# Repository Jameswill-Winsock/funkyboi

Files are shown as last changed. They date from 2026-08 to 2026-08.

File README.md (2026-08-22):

# funkyboi
a funky chonky handheld gba clone

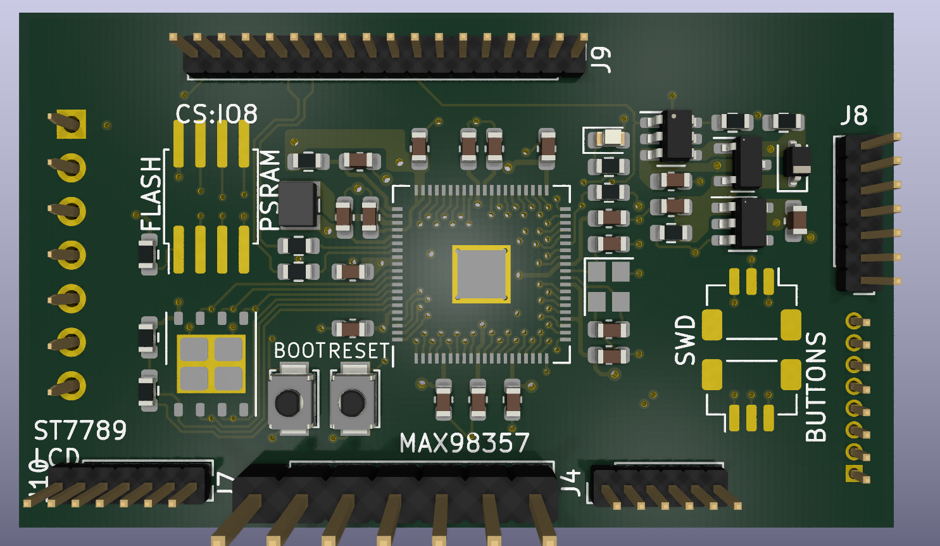
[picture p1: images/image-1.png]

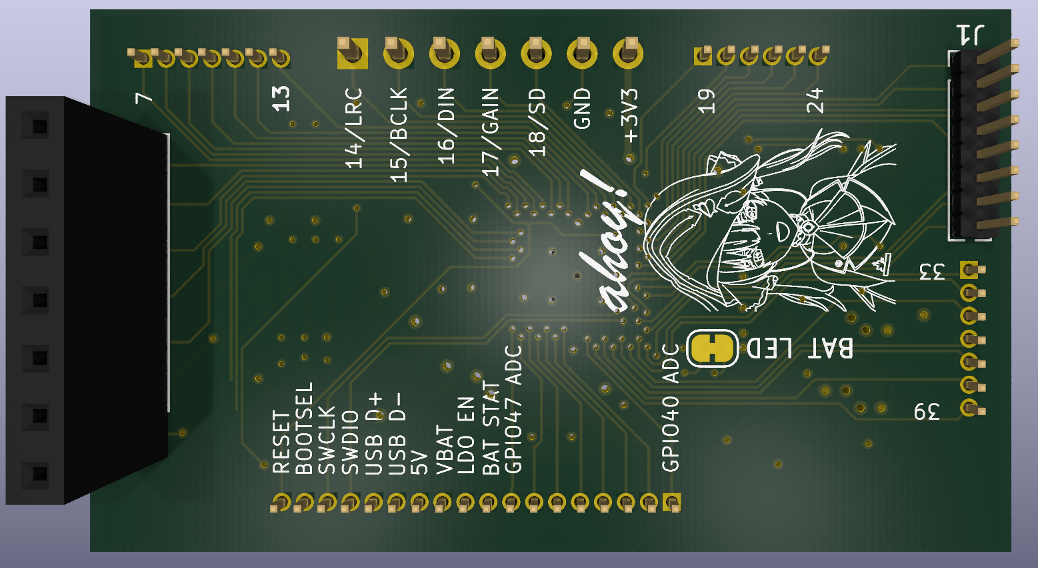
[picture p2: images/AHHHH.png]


he's a work in progress, please bear with him

## What is this?
like you read, a gba clone. its meant to be as small in form factor as possible, and currently i've nearly achieved this. 
it borrows from the solderparty stamp xl in form of the schematic, but pcb was remade because it wouldn't open for me for some reason. some differences between those and this are:
- lack of castelled edge based breakout (swapped to normal through holes)
- no proper power plane or signal plane (i have no idea how those work, i only know ground copper pour)
- power network significantly changed to be more unified (arguably, more unstable, but throw on some 100nf capacitors and it fixes everything.)
- the obvious gamer setup

## Parts used
please refer to "BOM reference.csv". Has everything for now,

## Journal.md
included please check

## Photos
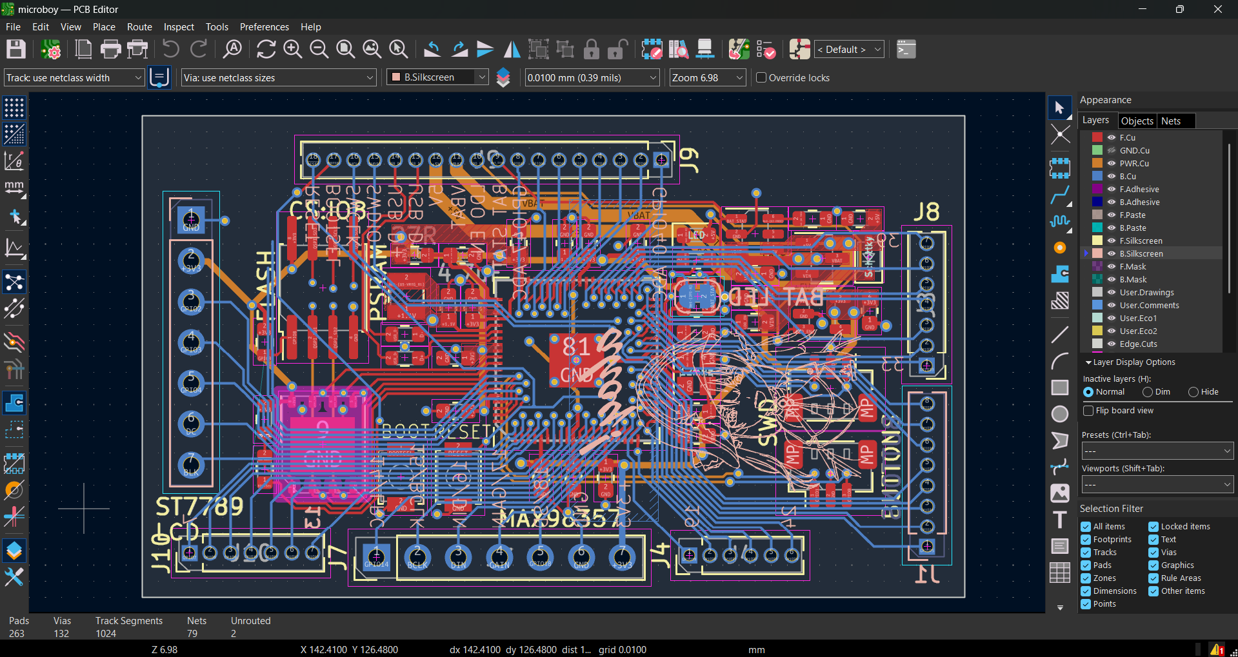
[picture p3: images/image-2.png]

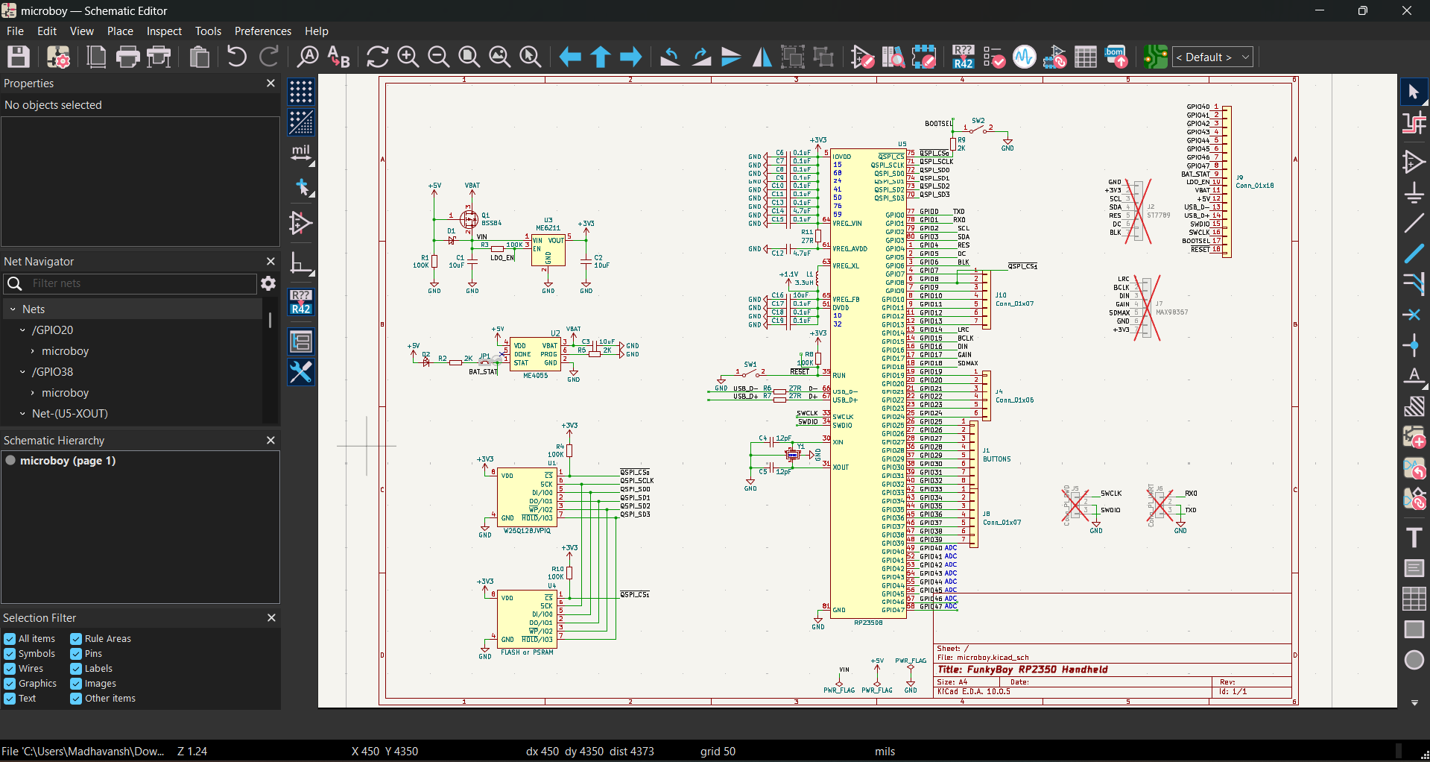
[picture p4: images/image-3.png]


yes i know the elephant in the room is the big red cross marks
they're marked do not populate because i want to leave the headers alone until i need them and for the actual parts that'll be needed i'll hand solder what i can

## Thanks
to you for coming here

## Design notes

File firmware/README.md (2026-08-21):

# Minimal bring-up firmware

quick and dirty test for the *funky* boi:
- ST7789V3 172x320 display on GPIO40..45
- 8 active-low buttons with pull-ups
- USB serial logging
- No PSRAM, flash filesystem, Doom, or audio yet

## Expected behavior
1. Boot -> LCD shows 8 color bars.
2. Then the loop goes black when no button is pressed.
3. Pressing each button fills the display with a unique color and prints button state over USB CDC serial.

## Pin map
LCD: MOSI 40, SCK 41, CS 42, DC 43, RST 44, BL 45
Buttons: UP 0, LEFT 1, RIGHT 2, DOWN 3, B 35, A 37, SELECT 18, START 24

## Build
Use a recent Raspberry Pi Pico SDK with RP2350 support.

```bash
mkdir build && cd build
cmake .. -DPICO_BOARD=pico2
make -j
```

Copy `microboy_bringup.uf2` to the RP2350 BOOTSEL drive.

## If the LCD is shifted / mirrored
This project assumes landscape 320x172 with a 34-pixel controller RAM offset and MADCTL=0x60.
If your panel orientation differs, adjust the MADCTL byte in `lcd_init()` and/or `yoff` in `lcd_window()`.

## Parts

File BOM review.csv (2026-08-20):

Reference | Value | Footprint | Qty | LCSC | Description
C4,C5 | 12pF | Capacitor_SMD:C_0603_1608Metric | 2
C6,C7,C8,C9,C10,C11,C13,C15,C17,C18,C19 | 0.1uF | Capacitor_SMD:C_0603_1608Metric | 11
L1 | 3.3uH | Inductor_SMD:L_Wuerth_MAPI-2512 | 1 | C5832359 | FTC252010S3R3MBCA
C12,C14 | 4.7uF | Capacitor_SMD:C_0603_1608Metric | 2
C1,C2,C3,C16 | 10uF | Capacitor_SMD:C_0603_1608Metric | 4
R6,R7,R11 | 27R | Resistor_SMD:R_0603_1608Metric | 3
R2,R5,R9 | 2K | Resistor_SMD:R_0603_1608Metric | 3
R1,R3,R4,R8,R10 | 100K | Resistor_SMD:R_0603_1608Metric | 5
SW8 | A | Button_Switch_SMD:SW_SPST_B3U-1000P | 1
SW7 | B | Button_Switch_SMD:SW_SPST_B3U-1000P | 1
Q1 | BSS84 | Package_TO_SOT_SMD:SOT-23 | 1 | C85202
Y1 | CM4012M00012001 | Crystal:Crystal_SMD_2520-4Pin_2.5x2.0mm | 1 | C7294611
J10,J11,J15,J16,J17,J19,J20 | Conn_01x01 | Connector_PinHeader_1.27mm:PinHeader_1x01_P1.27mm_Vertical | 7 |  | Generic connector, single row, 01x01, 1.27mm, through hole vertical
J9,J12,J13,J14,J18 | Conn_01x02 | Connector_PinHeader_1.27mm:PinHeader_1x02_P1.27mm_Vertical | 5 |  | Generic connector, single row, 01x02, 1.27mm, through hole vertical
J3 | Conn_01x05 | Connector_PinHeader_1.27mm:PinHeader_1x05_P1.27mm_Vertical | 1 |  | Generic connector, single row, 01x05, 1.27mm, through hole vertical
J1,J4 | Conn_01x10 | Connector_PinHeader_1.27mm:PinHeader_1x10_P1.27mm_Vertical | 2 |  | Generic connector, single row, 01x10, 1.27mm, through hole vertical
J5 | Conn_Pi_SWD | Connector_JST:JST_SH_BM03B-SRSS-TB_1x03-1MP_P1.00mm_Vertical | 1 | C7433439
J6 | Conn_Pi_UART | Connector_JST:JST_SH_BM03B-SRSS-TB_1x03-1MP_P1.00mm_Vertical | 1 | C7433439
D1 | D_Schottky_Small | Diode_SMD:D_SOD-323 | 1 | C114023 | B5817WS-SJ
SW6 | DOWN | Button_Switch_SMD:SW_SPST_B3U-1000P | 1
U4 | FLASH or PSRAM | Package_SO:SSOP-8_5.25x5.24mm_P1.27mm | 1
J8 | I2S_AUDIO | Connector_PinHeader_2.54mm:PinHeader_1x05_P2.54mm_Vertical | 1
J7 | LCD_ST7789 | Connector_PinHeader_2.54mm:PinHeader_1x08_P2.54mm_Vertical | 1
D2 | LED_CHR | LED_SMD:LED_0603_1608Metric | 1 |  | Orange
SW4 | LEFT | Button_Switch_SMD:SW_SPST_B3U-1000P | 1
U2 | ME4055 | Package_TO_SOT_SMD:SOT-23-6 | 1 | C82121
U3 | ME6211 | Package_TO_SOT_SMD:SOT-23-5 | 1 | C82942
SW5 | RIGHT | Button_Switch_SMD:SW_SPST_B3U-1000P | 1
U5 | RP2350B | Package_DFN_QFN_Extra:QFN-80_EP_10x10_Pitch0.4mm | 1
SW9 | SELECT | Button_Switch_SMD:SW_SPST_B3U-1000P | 1
SW10 | START | Button_Switch_SMD:SW_SPST_B3U-1000P | 1
SW2 | SW_BOOTSEL | Button_Switch_SMD:SW_SPST_B3U-1000P | 1 | C561514 | TS-3025-A-A-B
SW1 | SW_RESET | Button_Switch_SMD:SW_SPST_B3U-1000P | 1 | C561514 | TS-3025-A-A-B
SW3 | UP | Button_Switch_SMD:SW_SPST_B3U-1000P | 1
U1 | W25Q128JVPIQ | Package_SON:WSON-8-1EP_6x5mm_P1.27mm_EP3.4x4mm | 1 | C190862
LCD1 | Waveshare_1.47in_172x320_ST7789V3 |  | 1 |  | External Waveshare LCD module from supplied link; connects to existing J7 LCD_ST7789
AMP1 | MAX98357A_I2S_Audio_Module |  | 1 |  | External I2S mono Class-D amplifier module; connects to existing J8 I2S_AUDIO
SPK1 | 4R_3W_Speaker |  | 1 |  | External 4 ohm 2-3W speaker for MAX98357A OUT+/OUT-
USB1 | USB-C_5V_Power_Breakout |  | 1 |  | OPTION A: external USB-C 5V power breakout; connect VBUS to existing +5V input and GND to GND
J21 | USB_C_Receptacle_USB2.0_16P | Connector_USB:USB_C_Receptacle_HRO_TYPE-C-31-M-12 | 1 | C165948 | OPTION B: raw on-board USB-C receptacle; use instead of USB1
R12,R13 | 5.1K | Resistor_SMD:R_0603_1608Metric | 2 | C23186 | USB-C CC1/CC2 pull-down resistors; required only with raw J21 option
D3 | USBLC6-2SC6 | Package_TO_SOT_SMD:SOT-23-6 | 1 | C7519 | USB D+/D- ESD protection; use with raw USB-C data connection
J22 | BATTERY_1S | Connector_JST:JST_PH_B2B-PH-K_1x02_P2.00mm_Vertical | 1 | C131337 | JST-PH 2.0mm 2-pin connector for 1S LiPo or protected 18650 supply
BAT1 | 1S_LiPo_3.7V |  | 1 |  | OPTION A battery: protected 1S LiPo pack; capacity/size to suit enclosure
BT1 | 18650_Holder_1S |  | 1 |  | OPTION B battery: single 18650 holder
BMS1 | 1S_LiIon_Protection_BMS |  | 1 |  | 18650/cell only; protection-only BMS because existing ME4055 already handles charging
SW11 | POWER_ON_OFF | Button_Switch_SMD:SW_SPDT_CK_JS102011SAQN | 1 |  | SPDT slide power switch; can use existing LDO_EN/VIN/GND arrangement without changing core circuitry

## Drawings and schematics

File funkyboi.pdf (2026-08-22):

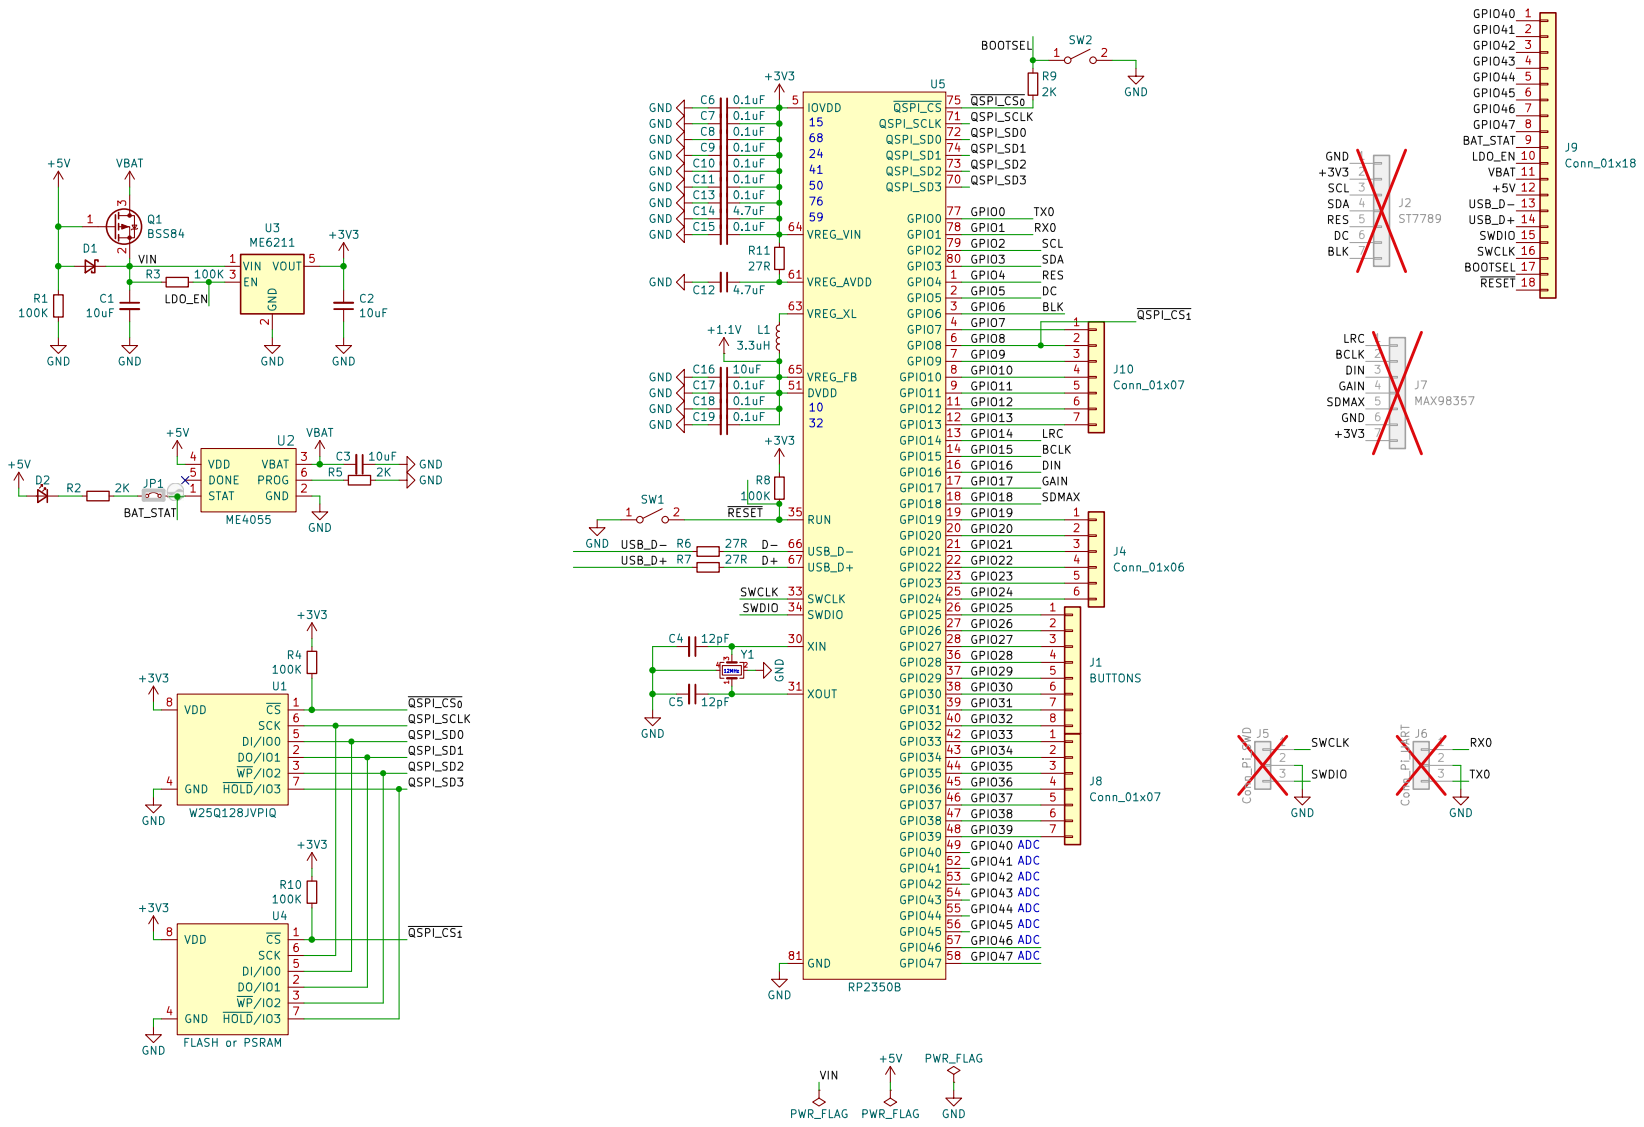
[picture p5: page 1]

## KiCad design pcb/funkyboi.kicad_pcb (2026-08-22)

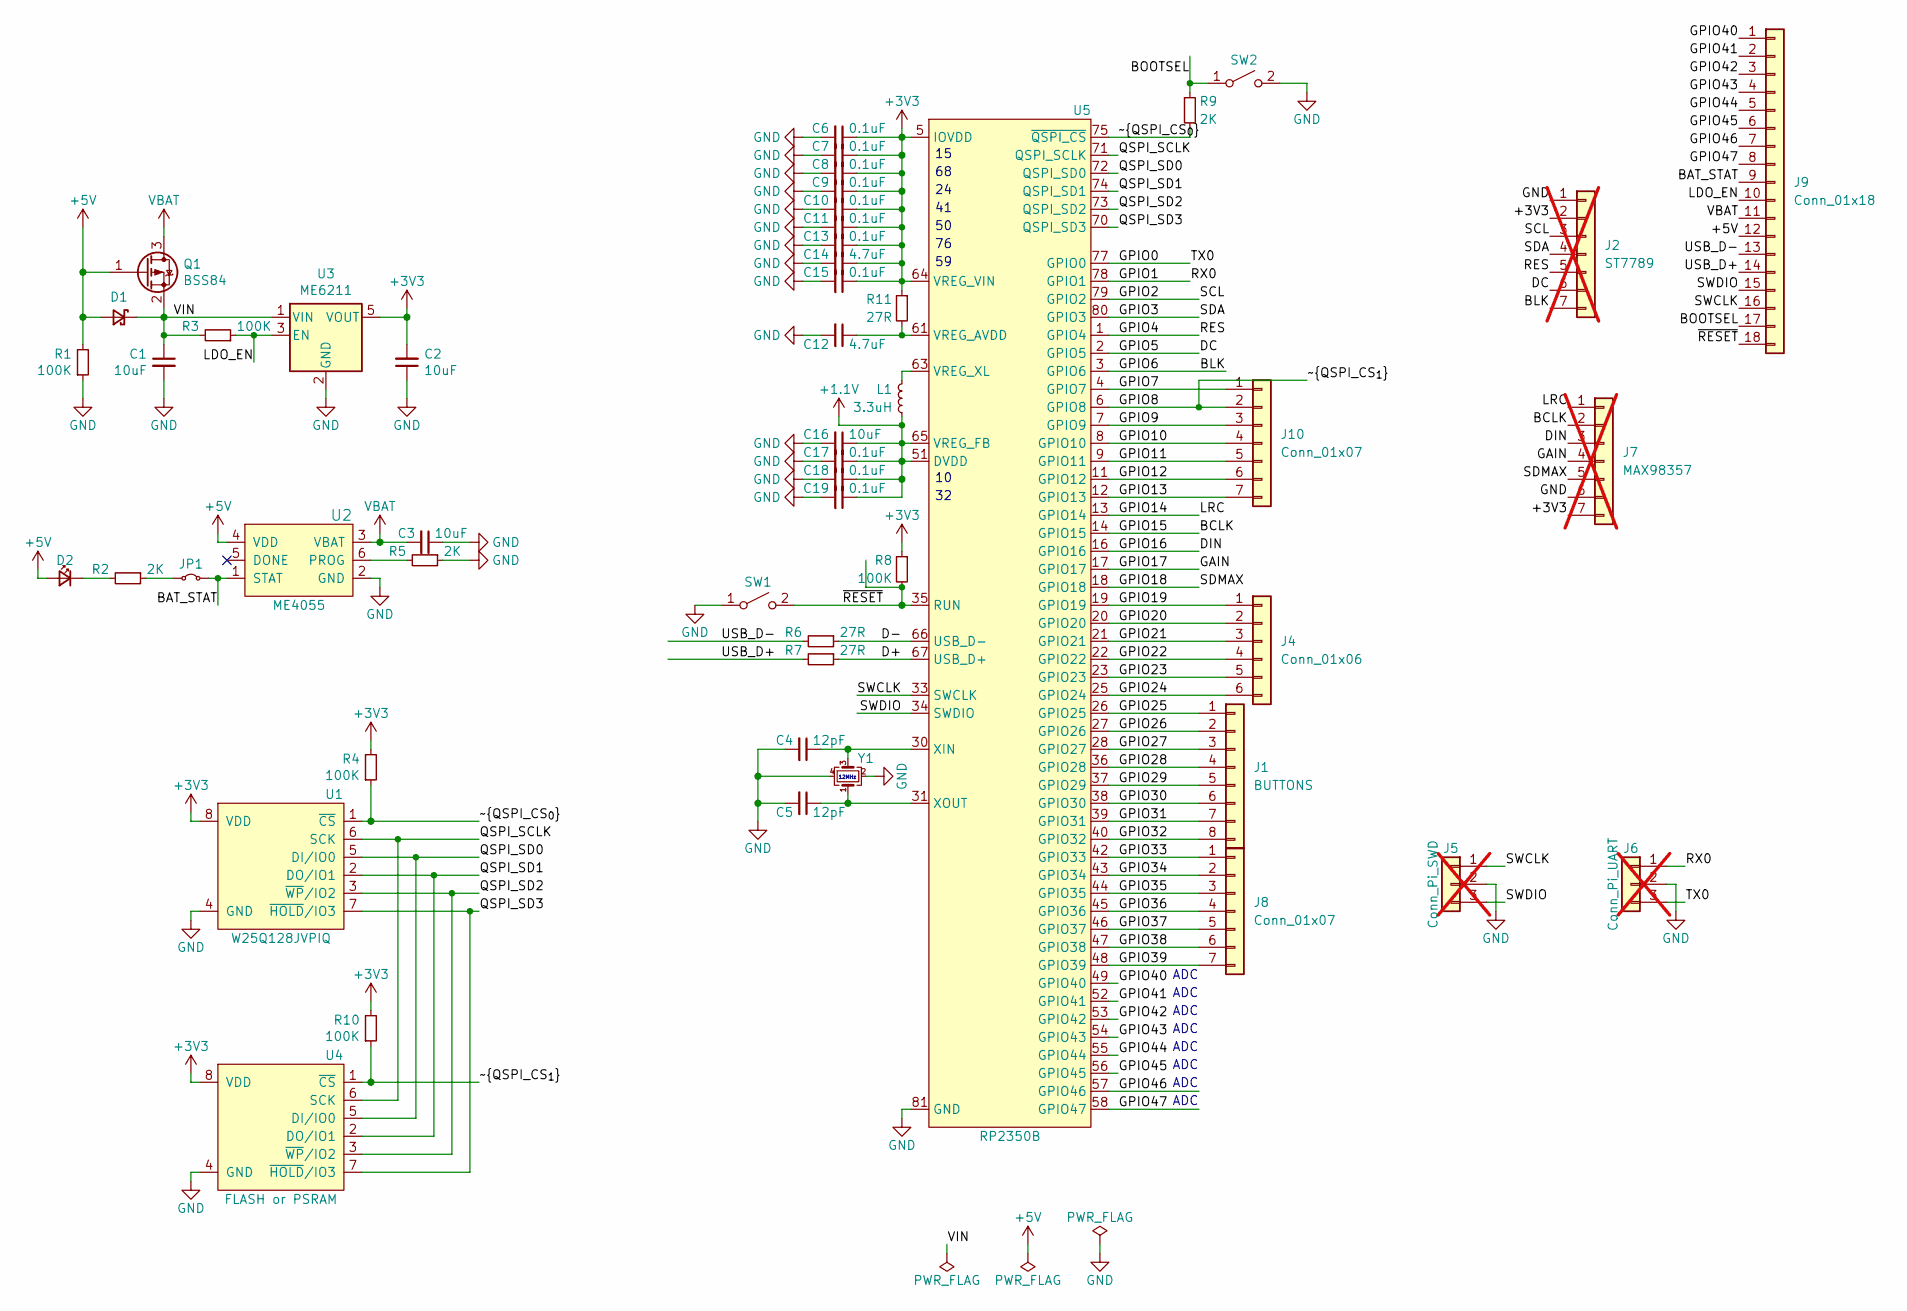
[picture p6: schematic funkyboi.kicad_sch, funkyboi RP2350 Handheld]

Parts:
C1, C2, C3, C16: 10uF; C_0603_1608Metric
C4, C5: 12pF; C_0603_1608Metric
C6, C7, C8, C9, C10, C11, C13, C15, C17, C18, C19: 0.1uF; C_0603_1608Metric
C12, C14: 4.7uF; C_0603_1608Metric
D1: D_Schottky_Small; D_SOD-323; LCSC C114023
D2: LED_CHR; LED_0603_1608Metric
J1: BUTTONS; PinHeader_1x08_P1.27mm_Vertical
J2: ST7789; PinSocket_1x07_P2.54mm_Vertical; not fitted
J4: Conn_01x06; PinHeader_1x06_P1.27mm_Vertical
J5: Conn_Pi_SWD; JST_SH_BM03B-SRSS-TB_1x03-1MP_P1.00mm_Vertical; LCSC C7433439; not fitted
J6: Conn_Pi_UART; JST_SH_BM03B-SRSS-TB_1x03-1MP_P1.00mm_Vertical; LCSC C7433439; not fitted
J7: MAX98357; PinHeader_1x07_P2.54mm_Vertical; not fitted
J8, J10: Conn_01x07; PinHeader_1x07_P1.27mm_Vertical
J9: Conn_01x18; PinHeader_1x18_P1.27mm_Vertical
JP1: SJ_STAT_LED; SolderJumper-2_P1.3mm_Bridged_RoundedPad1.0x1.5mm
L1: 3.3uH; L_Wuerth_MAPI-2512; LCSC C5832359
Q1: BSS84; SOT-23; LCSC C85202
R1, R3, R4, R8, R10: 100K; R_0603_1608Metric
R2, R5, R9: 2K; R_0603_1608Metric
R6, R7, R11: 27R; R_0603_1608Metric
SW1: SW_RESET; SW_SPST_B3U-1000P; LCSC C561514
SW2: SW_BOOTSEL; SW_SPST_B3U-1000P; LCSC C561514
U1: W25Q128JVPIQ; WSON-8-1EP_6x5mm_P1.27mm_EP3.4x4mm; LCSC C190862
U2: ME4055; SOT-23-6; LCSC C82121
U3: ME6211; SOT-23-5; LCSC C82942
U4: FLASH or PSRAM; SSOP-8_5.25x5.24mm_P1.27mm
U5: RP2350B; QFN-80_EP_10x10_Pitch0.4mm
Y1: CM4012M00012001; Crystal_SMD_2520-4Pin_2.5x2.0mm; LCSC C7294611

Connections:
+1.1V: C16.1, C17.1, C18.1, C19.1, L1.1, U5.10 (DVDD), U5.32 (DVDD), U5.51 (DVDD), U5.65 (VREG_FB)
+3V3: C2.2, C6.1, C7.1, C8.1, C9.1, C10.1, C11.1, C13.1, C14.1, C15.1, J2.2, J7.7, R4.2, R8.1, R10.2, R11.1, U1.8 (VDD), U3.5 (VOUT), U4.8 (VDD), U5.5 (IOVDD), U5.15 (IOVDD), U5.24 (IOVDD), U5.29 (IOVDD), U5.41 (IOVDD), U5.50 (IOVDD), U5.59 (IOVDD), U5.60 (IOVDD), U5.64 (VREG_VIN), U5.68 (IOVDD), U5.69 (IOVDD), U5.76 (IOVDD)
+5V: D1.2 (A), D2.2 (A), J9.12, Q1.1 (G), R1.2, U2.4 (VDD)
/BAT_STAT: J9.9, JP1.2 (B), U2.1 (STAT)
/BCLK: J7.2, U5.14 (GPIO15)
/BLK: J2.7, U5.3 (GPIO6)
/BOOTSEL: J9.17, R9.1, SW2.1 (A)
/D+: R7.1, U5.67 (USB_D+)
/D-: R6.1, U5.66 (USB_D-)
/DC: J2.6, U5.2 (GPIO5)
/DIN: J7.3, U5.16 (GPIO16)
/GAIN: J7.4, U5.17 (GPIO17)
/GPIO0: J6.3, U5.77 (GPIO0)
/GPIO1: J6.1, U5.78 (GPIO1)
/GPIO2: J2.3, U5.79 (GPIO2)
/GPIO3: J2.4, U5.80 (GPIO3)
/GPIO4: J2.5, U5.1 (GPIO4)
/GPIO7: J10.1, U5.4 (GPIO7)
/GPIO8: J10.2, R10.1, U4.1 (~CS), U5.6 (GPIO8)
/GPIO9: J10.3, U5.7 (GPIO9)
/GPIO10: J10.4, U5.8 (GPIO10)
/GPIO11: J10.5, U5.9 (GPIO11)
/GPIO12: J10.6, U5.11 (GPIO12)
/GPIO13: J10.7, U5.12 (GPIO13)
/GPIO14: J7.1, U5.13 (GPIO14)
/GPIO18: J7.5, U5.18 (GPIO18)
/GPIO19: J4.1, U5.19 (GPIO19)
/GPIO20: J4.2, U5.20 (GPIO20)
/GPIO21: J4.3, U5.21 (GPIO21)
/GPIO22: J4.4, U5.22 (GPIO22)
/GPIO23: J4.5, U5.23 (GPIO23)
/GPIO24: J4.6, U5.25 (GPIO24)
/GPIO25: J1.1, U5.26 (GPIO25)
/GPIO26: J1.2, U5.27 (GPIO26)
/GPIO27: J1.3, U5.28 (GPIO27)
/GPIO28: J1.4, U5.36 (GPIO28)
/GPIO29: J1.5, U5.37 (GPIO29)
/GPIO30: J1.6, U5.38 (GPIO30)
/GPIO31: J1.7, U5.39 (GPIO31)
/GPIO32: J1.8, U5.40 (GPIO32)
/GPIO33: J8.1, U5.42 (GPIO33)
/GPIO34: J8.2, U5.43 (GPIO34)
/GPIO35: J8.3, U5.44 (GPIO35)
/GPIO36: J8.4, U5.45 (GPIO36)
/GPIO37: J8.5, U5.46 (GPIO37)
/GPIO38: J8.6, U5.47 (GPIO38)
/GPIO39: J8.7, U5.48 (GPIO39)
/GPIO40: J9.1, U5.49 (GPIO40)
/GPIO41: J9.2, U5.52 (GPIO41)
/GPIO42: J9.3, U5.53 (GPIO42)
/GPIO43: J9.4, U5.54 (GPIO43)
/GPIO44: J9.5, U5.55 (GPIO44)
/GPIO45: J9.6, U5.56 (GPIO45)
/GPIO46: J9.7, U5.57 (GPIO46)
/GPIO47: J9.8, U5.58 (GPIO47)
/LDO_EN: J9.10, R3.1, U3.3 (EN)
/QSPI_SCLK: U1.6 (SCK), U4.6 (SCK), U5.71 (QSPI_SCLK)
/QSPI_SD0: U1.5 (DI/IO0), U4.5 (DI/IO0), U5.72 (QSPI_SD0)
/QSPI_SD1: U1.2 (DO/IO1), U4.2 (DO/IO1), U5.74 (QSPI_SD1)
/QSPI_SD2: U1.3 (~WP/IO2), U4.3 (~WP/IO2), U5.73 (QSPI_SD2)
/QSPI_SD3: U1.7 (~HOLD/IO3), U4.7 (~HOLD/IO3), U5.70 (QSPI_SD3)
/SWCLK: J5.1, J9.16, U5.33 (SWCLK)
/SWDIO: J5.3, J9.15, U5.34 (SWDIO)
/USB_D+: J9.14, R7.2
/USB_D-: J9.13, R6.2
/VIN: C1.1, D1.1 (K), Q1.2 (S), R3.2, U3.1 (VIN)
/~QSPI_CS_{0}: R4.1, R9.2, U1.1 (~CS), U5.75 (~QSPI_CS)
/~RESET: J9.18, R8.2, SW1.2 (B), U5.35 (RUN)
GND: C1.2, C2.1, C3.1, C4.2, C5.2, C6.2, C7.2, C8.2, C9.2, C10.2, C11.2, C12.2, C13.2, C14.2, C15.2, C16.2, C17.2, C18.2, C19.2, J2.1, J5.2, J6.2, J7.6, R1.1, R5.1, SW1.1 (A), SW2.2 (B), U1.4 (GND), U1.9 (GND), U2.2 (GND), U3.2 (GND), U4.4 (GND), U4.9 (GND), U5.62 (GND), U5.81 (GND), Y1.2, Y1.4
unnamed: D2.1 (K), R2.2
unnamed: JP1.1 (A), R2.1
unnamed: R5.2, U2.6 (PROG)
unnamed: C12.1, R11.2, U5.61 (VREG_AVDD)
unnamed: L1.2, U5.63 (VREG_XL)
unnamed: C4.1, U5.30 (XIN), Y1.3
unnamed: C5.1, U5.31 (XOUT), Y1.1
VBAT: C3.2, J9.11, Q1.3 (D), U2.3 (VBAT)

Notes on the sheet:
ADC
12MHz

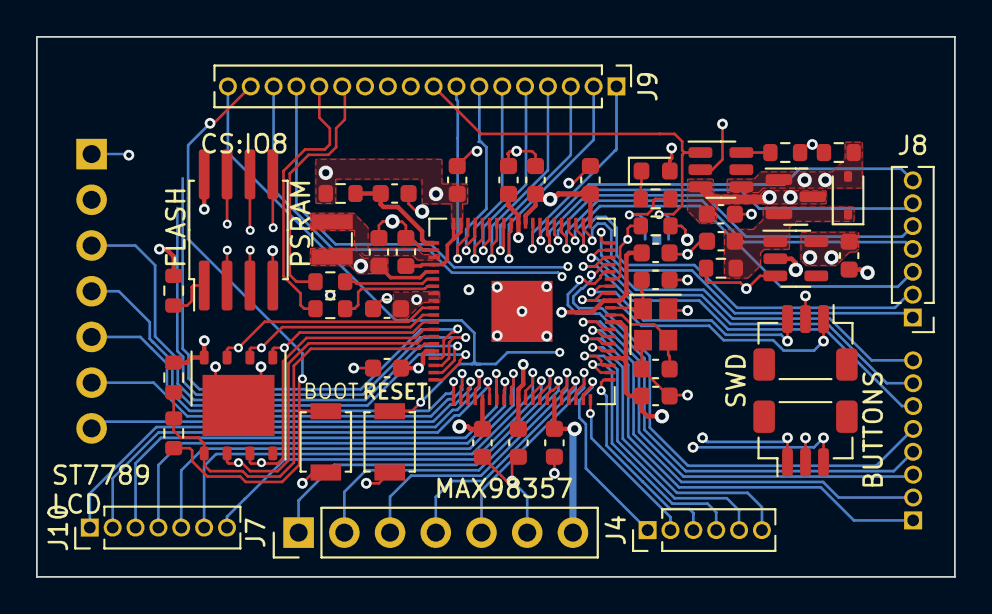
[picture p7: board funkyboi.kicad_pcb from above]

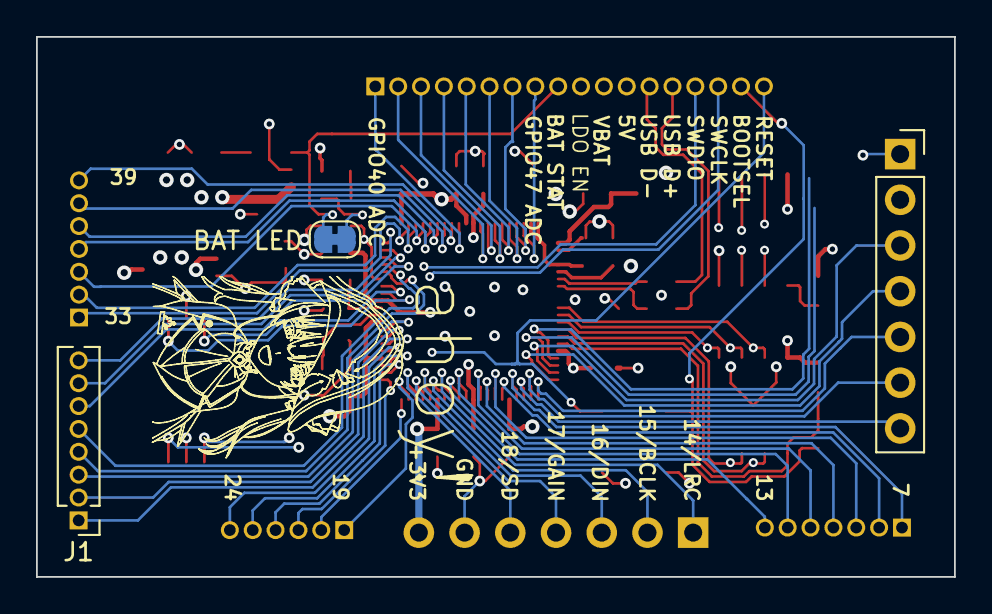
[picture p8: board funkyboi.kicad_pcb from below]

Board: 4 copper layers, 51.0 x 30.0 mm, 52 parts (3 on the bottom side), 77 nets.

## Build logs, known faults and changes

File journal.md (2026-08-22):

ea
# Guerilla speedrun hackathon - my experience

### 19/08/2026 and 20/08/2026 IST

Genuine banger of an event. I did spend so many hours holed up like a hobbit routing pcb like a mad man, but hey, its pretty cool.

Originally, I wanted to do an 8088 carrier motherboard, using RP2040 as carriers, but when I started doing that....... it need like 8 different level shifters and two other ICs for handling the bus line.


yeahhhhhhh............... aint nobody handling this in two days. this stuff will atleast take me a week. 


here you can witness the glorious ratsnest that i still havent wired up. 

So I switched to an idea of mine recently to make a small handheld gameboy/gba clone. Admittedly, its not as small as i expected it to be.... but that comes with time, and this was just 48 hours xd.

What I did first was to start the schematic, and build stuff as normal. That took no time. (i mean, looking up references from other boards does make your job very easy) The issue came when I started designing the PCB. I first decided I would go with a 2 layer pcb - despite clearly needing a 4 layer and spent time trying to jump crossing traces using 0 ohm resistors.
Clearly, that did not last long. So here I am, building my first four layer pcb. Interesting idea to put an entire layer full of copper as ground, and another just for handling your power. Guess you learn something new every day.

Then I ran into another thing. Apparently, you're not supposed to wire your traces hodge podge with mismatched trace lengths and instead keep them as close and symmetric as you can. Not so surprising, but the first time it hits like a truck.
Finally, I finished the difficult part of power delivery, USB, SWD, and the main RP2350B. In all that fun..... I forgot i had to actually build a handheld game device, not just a cool carrier board for the pico. Hence the chonky and funky boi.

I do have to say though, jumping layers using traces is more intuitive, even more so in 4 layer than 2, partly because you see the use of it so much more than in 2. Much useful. 

The reason to leave pin headers littered all over the place is simple: I want to leave the ability to expand this board later in the future using daughterboards, hence the free space next to the pcb for mounting a board later if needed be.
Had to end up using 1.27mm ones because 2.54mm would not fit. I made the core system too small lol.


i am pretty proud of this one, 'tis nice

The next part will be to make this as concise as possible, and live up to its true name of a funky micro boy and less chonky.

Total hours spent: approx 10 hours.

### 21/08/2026 IST
In order to get it approved, I was asked to make it smaller and less chonky. Sure, I had to do that anyways, and if I get time for that too? Heck yeah. So I started shrinking it.

The first part was to replace the screen. It was kinda too big earlier, so I swapped it out with a square 0.96 inch oled. The buttons are also taken off board and will be mounted on top of the pcb via mounting holes onto a protoboard, so theres that. Space reduction was made mainly vertical, like how the new oled will be mounted using the pin headers as its supports.

Next, the pcb. Its traces were stretched too far out earlier because of all the buttons and screen. Now that they were gone, I could shrink this down easily. GPIO has also been placed closer in, but instead for the GPIO expansion for later, I've opted to use 1.27mm headers instead of 2.54mm standard headers to save space. Similarly, because of all the rearrangement, I've also had to redo the pins and pick other ones (including the correct ones this time for SCL and SDA for the display lmao)

Afterwards I added all the silkscreen stuff. Also converted my profile picture drawing to vector, then cleaned it up. Makes a nice addition. Senchou is love senchou is life :3



*I said, "Better late than never*<br>
*Just don't make me wait forever"*

Total hours spent: approx 5 hours.

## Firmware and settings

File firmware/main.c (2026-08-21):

#include <stdio.h>
#include "pico/stdlib.h"
#include "hardware/clocks.h"

// ---------------- funkyboi pin map ----------------
#define PIN_LCD_MOSI 40
#define PIN_LCD_SCK  41
#define PIN_LCD_CS   42
#define PIN_LCD_DC   43
#define PIN_LCD_RST  44
#define PIN_LCD_BL   45

#define PIN_UP       0
#define PIN_LEFT     1
#define PIN_RIGHT    2
#define PIN_DOWN     3
#define PIN_B        35
#define PIN_A        37
#define PIN_SELECT   18
#define PIN_START    24

#define LCD_W 320
#define LCD_H 172

static inline void lcd_cs(bool high)  { gpio_put(PIN_LCD_CS, high); }
static inline void lcd_dc(bool high)  { gpio_put(PIN_LCD_DC, high); }
static inline void lcd_sck(bool high) { gpio_put(PIN_LCD_SCK, high); }
static inline void lcd_mosi(bool high){ gpio_put(PIN_LCD_MOSI, high); }

// Slow-but-simple SPI bitbang for first board bring-up.
static void spi_write8(uint8_t v) {
    for (int i = 7; i >= 0; --i) {
        lcd_sck(false);
        lcd_mosi((v >> i) & 1);
        __asm volatile("nop\n nop\n");
        lcd_sck(true);
        __asm volatile("nop\n nop\n");
    }
    lcd_sck(false);
}

static void lcd_cmd(uint8_t c) {
    lcd_cs(false);
    lcd_dc(false);
    spi_write8(c);
    lcd_cs(true);
}

static void lcd_data8(uint8_t d) {
    lcd_cs(false);
    lcd_dc(true);
    spi_write8(d);
    lcd_cs(true);
}

static void lcd_data(const uint8_t *p, size_t n) {
    lcd_cs(false);
    lcd_dc(true);
    while (n--) spi_write8(*p++);
    lcd_cs(true);
}

static void lcd_reset(void) {
    gpio_put(PIN_LCD_RST, 1);
    sleep_ms(10);
    gpio_put(PIN_LCD_RST, 0);
    sleep_ms(20);
    gpio_put(PIN_LCD_RST, 1);
    sleep_ms(120);
}

static void lcd_init(void) {
    gpio_put(PIN_LCD_BL, 0);
    lcd_reset();

    lcd_cmd(0x01); // SWRESET
    sleep_ms(150);
    lcd_cmd(0x11); // SLPOUT
    sleep_ms(120);

    // 16-bit RGB565
    lcd_cmd(0x3A);
    lcd_data8(0x55);

    // Landscape orientation. If mirrored/upside-down, try 0xA0 / 0x60 / 0xC0.
    lcd_cmd(0x36);
    lcd_data8(0x60);

    // Normal display on, inversion on is common for ST7789 panels.
    lcd_cmd(0x21);
    lcd_cmd(0x13);
    lcd_cmd(0x29);
    sleep_ms(20);

    gpio_put(PIN_LCD_BL, 1);
}

static void lcd_window(uint16_t x0, uint16_t y0, uint16_t x1, uint16_t y1) {
    // For 172x320 glass in landscape, controller RAM is offset by 34 rows.
    const uint16_t yoff = 34;
    y0 += yoff;
    y1 += yoff;

    uint8_t b[4];
    lcd_cmd(0x2A); // CASET
    b[0] = x0 >> 8; b[1] = x0; b[2] = x1 >> 8; b[3] = x1;
    lcd_data(b, 4);

    lcd_cmd(0x2B); // RASET
    b[0] = y0 >> 8; b[1] = y0; b[2] = y1 >> 8; b[3] = y1;
    lcd_data(b, 4);

    lcd_cmd(0x2C); // RAMWR
}

static void lcd_fill(uint16_t color) {
    lcd_window(0, 0, LCD_W - 1, LCD_H - 1);
    lcd_cs(false);
    lcd_dc(true);
    uint8_t hi = color >> 8, lo = color & 0xff;
    for (int i = 0; i < LCD_W * LCD_H; ++i) {
        spi_write8(hi);
        spi_write8(lo);
    }
    lcd_cs(true);
}

static void lcd_color_bars(void) {
    const uint16_t colors[] = {
        0xF800, // red
        0x07E0, // green
        0x001F, // blue
        0xFFE0, // yellow
        0x07FF, // cyan
        0xF81F, // magenta
        0xFFFF, // white
        0x0000  // black
    };
    const int n = (int)(sizeof(colors)/sizeof(colors[0]));
    const int bar_h = LCD_H / n;

    for (int bar = 0; bar < n; ++bar) {
        int y0 = bar * bar_h;
        int y1 = (bar == n - 1) ? (LCD_H - 1) : (y0 + bar_h - 1);
        lcd_window(0, y0, LCD_W - 1, y1);
        lcd_cs(false);
        lcd_dc(true);
        uint8_t hi = colors[bar] >> 8, lo = colors[bar] & 0xff;
        for (int i = 0; i < LCD_W * (y1 - y0 + 1); ++i) {
            spi_write8(hi);
            spi_write8(lo);
        }
        lcd_cs(true);
    }
}

static void button_init(int pin) {
    gpio_init(pin);
    gpio_set_dir(pin, GPIO_IN);
    gpio_pull_up(pin);
}

static bool pressed(int pin) {
    return gpio_get(pin) == 0;
}

static uint16_t color_from_buttons(void) {
    if (pressed(PIN_A))      return 0xF800; // red
    if (pressed(PIN_B))      return 0x001F; // blue
    if (pressed(PIN_UP))     return 0x07E0; // green
    if (pressed(PIN_DOWN))   return 0xFFE0; // yellow
    if (pressed(PIN_LEFT))   return 0x07FF; // cyan
    if (pressed(PIN_RIGHT))  return 0xF81F; // magenta
    if (pressed(PIN_SELECT)) return 0xFFFF; // white
    if (pressed(PIN_START))  return 0x8410; // gray
    return 0x0000;
}

int main(void) {
    stdio_init_all();
    sleep_ms(500);

    // LCD GPIO
    const int outs[] = {PIN_LCD_MOSI, PIN_LCD_SCK, PIN_LCD_CS, PIN_LCD_DC, PIN_LCD_RST, PIN_LCD_BL};
    for (unsigned i = 0; i < sizeof(outs)/sizeof(outs[0]); ++i) {
        gpio_init(outs[i]);
        gpio_set_dir(outs[i], GPIO_OUT);
        gpio_put(outs[i], 0);
    }
    gpio_put(PIN_LCD_CS, 1);
    gpio_put(PIN_LCD_RST, 1);

    // Buttons
    button_init(PIN_UP);
    button_init(PIN_LEFT);
    button_init(PIN_RIGHT);
    button_init(PIN_DOWN);
    button_init(PIN_B);
    button_init(PIN_A);
    button_init(PIN_SELECT);
    button_init(PIN_START);

    lcd_init();
    lcd_color_bars();

    printf("funkyboi bring-up started. sys_clk=%u Hz\n", clock_get_hz(clk_sys));
    printf("Press buttons: screen color changes and USB serial prints state.\n");

    uint16_t last = 0xFFFF;
    uint32_t last_mask = 0xFFFFFFFFu;

    while (true) {
        uint32_t mask = 0;
        mask |= pressed(PIN_UP)     << 0;
        mask |= pressed(PIN_LEFT)   << 1;
        mask |= pressed(PIN_RIGHT)  << 2;
        mask |= pressed(PIN_DOWN)   << 3;
        mask |= pressed(PIN_B)      << 4;
        mask |= pressed(PIN_A)      << 5;
        mask |= pressed(PIN_SELECT) << 6;
        mask |= pressed(PIN_START)  << 7;

        uint16_t c = color_from_buttons();
        if (c != last) {
            lcd_fill(c);
            last = c;
        }

        if (mask != last_mask) {
            printf("buttons: U%d L%d R%d D%d B%d A%d SEL%d START%d\n",
                !!(mask & 1), !!(mask & 2), !!(mask & 4), !!(mask & 8),
                !!(mask & 16), !!(mask & 32), !!(mask & 64), !!(mask & 128));
            last_mask = mask;
        }

        sleep_ms(20);
    }
}

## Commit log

2026-08-20 add the review bom
    iz more human readable than the kicad one
    [BOM review.csv]
2026-08-21 added firmware, repo overahuled for ship
    [BOM.csv, funkyboi.kicad_pcb, funkyboi.kicad_sch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]
2026-08-21 Add Pico Build Action to CMake workflow
2026-08-22 revision 1 update
    [funkyboi.kicad_pcb, funkyboi.kicad_sch]
